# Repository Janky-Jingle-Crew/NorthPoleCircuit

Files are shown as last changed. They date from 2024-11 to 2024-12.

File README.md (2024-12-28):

{% comment %}

# North Pole Circuit
Also available on [janky-jingle-crew.com/NorthPoleCircuit](https://janky-jingle-crew.com/NorthPoleCircuit/)

{% endcomment %}

Merry Christmas, and a Happy New Year! This year, we present the first *Dual-core, 32-bit, high-speed, RISC-V, USB-C, hyper-festive, magnetic propulsion **christmas card!***

North Pole Circuit (https://www.youtube.com/watch?v=rN7HYXmgxzk)

(Click on image to watch demo video)

Featured on [Hackaday.com](https://hackaday.com/?p=739494), [hackster.io](https://www.hackster.io/news/racing-toward-christmas-4728aa6665af)

## User Guide

Plug in a USB-C cable, place the card on a flat surface, and put the deer and the sleigh onto the track. The three buttons at the bottom control the speed, there are three levels for each direction. The upper music button plays a Christmas Jingle accompanied by a small "dance".

## Working Principle
The propulsion can by explained by the reaction force from the [Lorentz force law](https://en.wikipedia.org/wiki/Lorentz_force) or [Magnetic forces](https://en.wikipedia.org/wiki/Force_between_magnets#Magnetic_force_due_to_non-uniform_magnetic_field), which acts orthogonally to the directions of both the current flow and the magnetic field of the magnet. Both seem to give the correct force vector, maybe someone smarter can figure out which one it actually is. By using magnets with poles aligned vertically (top and bottom) and positioning the PCB traces perpendicular to the track’s direction, the magnets experience a forward or backward force along the track based on the current direction.

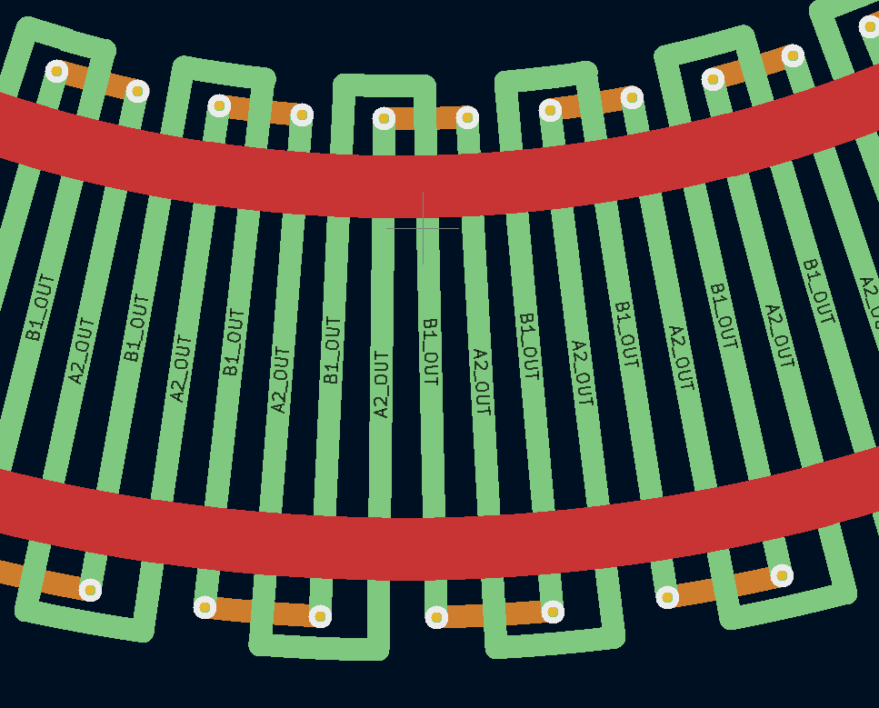
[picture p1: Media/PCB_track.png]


The tracks (A and B) are driven with two sinusoidal waveforms with a 90-degree phase shift between them, similar to microstepping a bipolar stepper motor. A guard rail is also added to keep the magnets centered during curves. The guard rails run along the outside of the track (parallel with track direction) which means an inwards force is generated instead. Reverse propulsion is achieved by simply stepping the sinusoidal in the other direction.
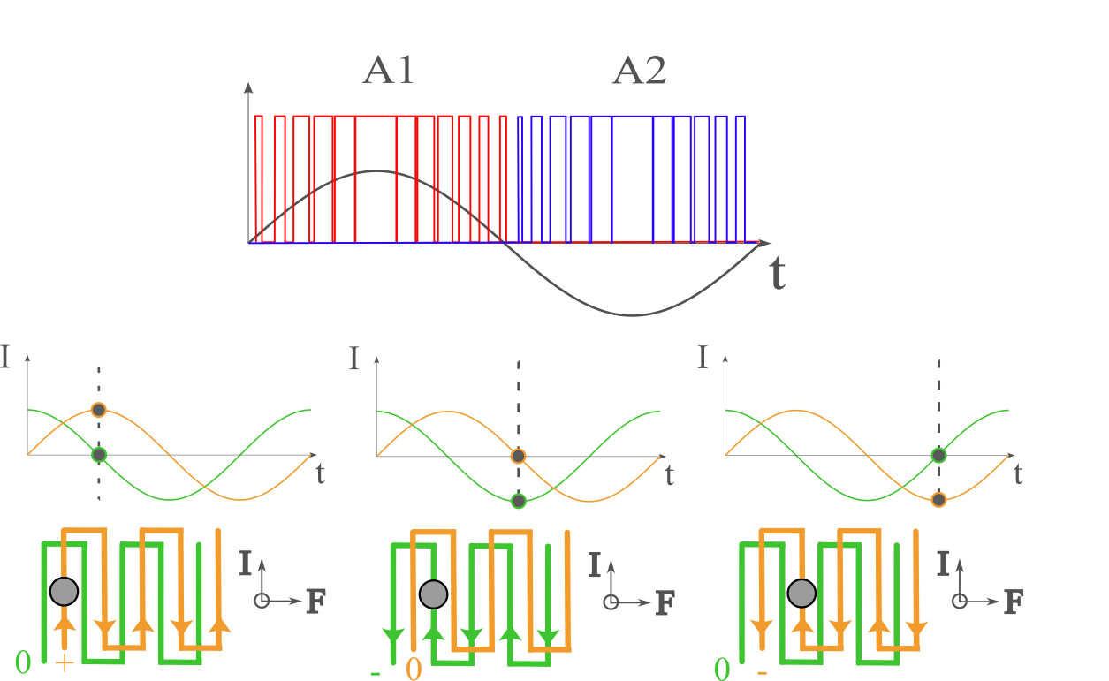
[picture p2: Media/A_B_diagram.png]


For more detailed explanations of the working principles, refer to **Jeff McBride’s** [blog post](https://jeffmcbride.net/gauss-speedway/).

## Design
The PCB consists of the phase tracks, guard rail, driver circuit and decoration circuit. The phases and guard rail are generated by Jeff's [curvycad](https://github.com/mcbridejc/curvycad/tree/main) plugin for KiCad. A 4 layer board was used for this, with 1 oz inner copper weight to reduce phase resistance. The driver circuit and the decoration circuit each have their own CH32 microcontroller, which communicate with each other using I2C. This was mainly done because a lack of timer modules.

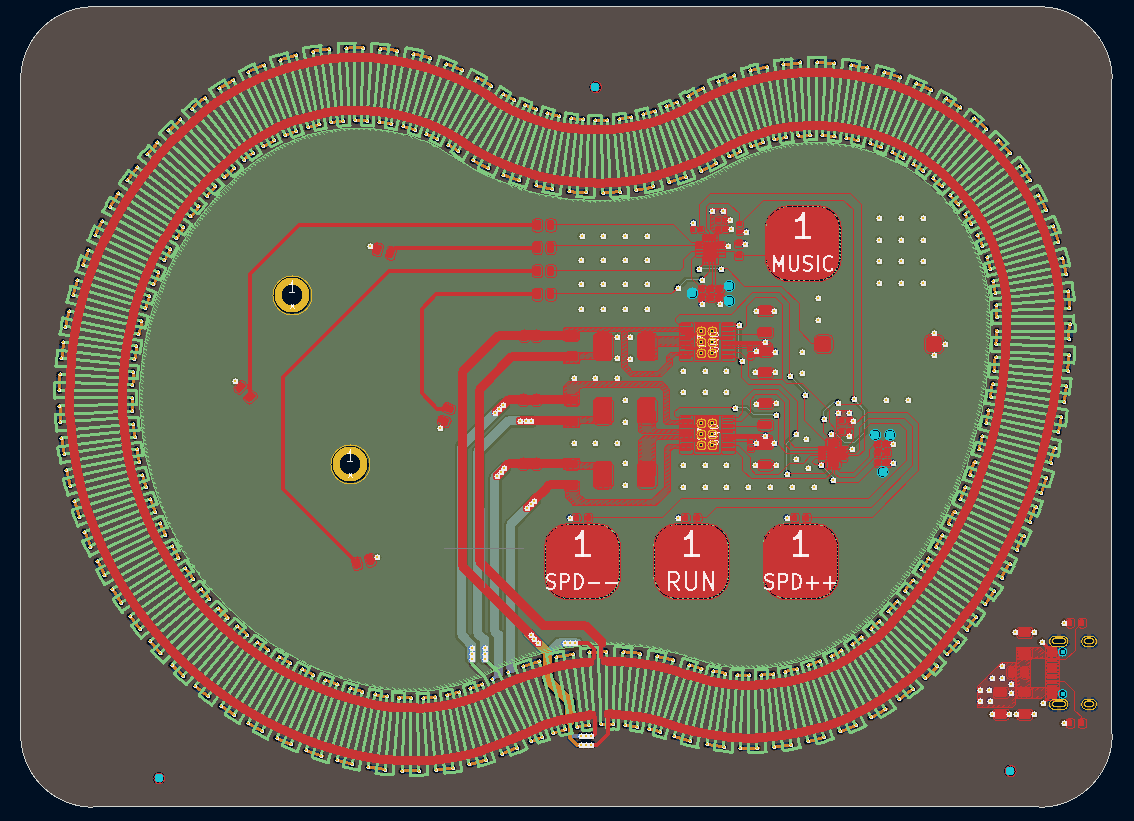
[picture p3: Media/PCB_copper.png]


### Driver circuit
The driver circuit controls the phase tracks and guard rails. The design is heavily based on Jeff’s design with some modifications for cost-effectiveness and USB compatibility:

* Power Supply: Utilizes 5V USB-C input instead of a barrel jack plug. The total current draw when moving is 500 mA.
* Microcontroller: Replaces the STM32 with the CH32V003, which is cheaper, ~20 cents! It is also 5V compatible.
* Motor Drivers: Uses DRV8833 motor drivers instead of ZXBM5210 for lower driver resistance (0.3 Ohms vs 1.2 Ohms), making the track a bit more efficient.

### Decoration circuit
A separate circuit using another CH32V003 handles LED control and buzzer music.

* CH32V003 microcontroller: Used for controlling decorative elements.
* I2C Communication: Links the decoration circuit with the driver circuit to synchronize dance.
* Buzzer: Plays a short Christmas jingle.
* LEDs: PWM brightness control through GPIOs for the 3D-printed village decoration. 

## Manufacturing

This year we made a total of 50 cards, all manufactured and assembled by JLC PCB. Each PCB then had decorations with trees and cottages attached, got rubber feet mounted, had one sleigh and one deer attached, was programmed, and was finally tested.

   

### Trees and cottages
The trees, cottage and ground are all one solid 3D-print, with a touch of white matte primer spray paint from above. Here, it is printed in 'army brown' PLA @ 0.2 mm layer height. Rectangular holes under the cottages give space for LEDs to illuminate them. This print was mounted to the PCB with 2 * M2.5x4mm screws.

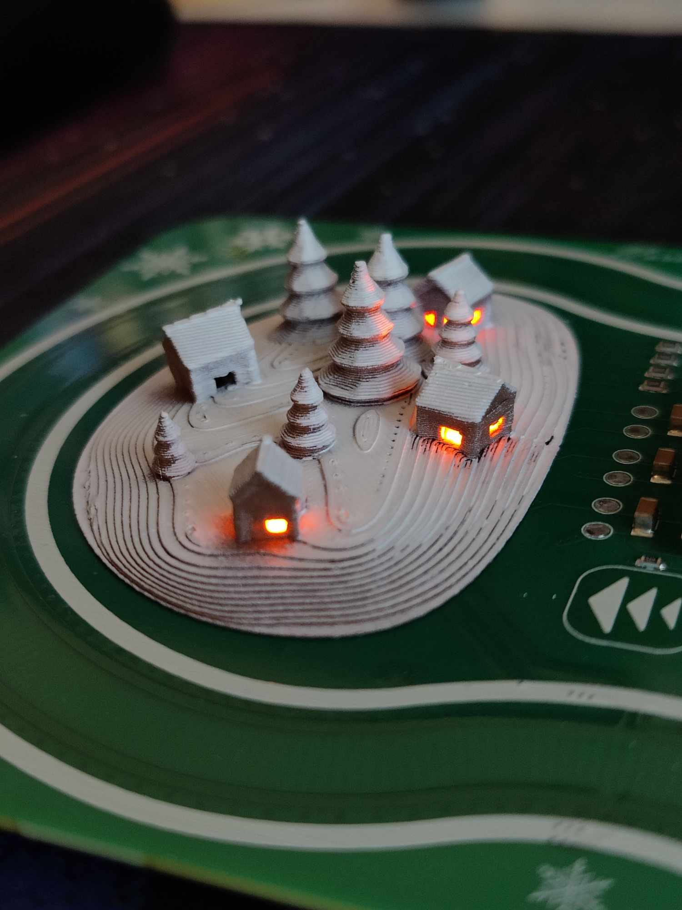
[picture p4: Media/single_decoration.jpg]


### Sleigh and reindeer
The sleigh and reindeer are also 3D-printed, but are a bit different. The sleigh is one print with multiple filaments, while the deer consists of two different; a white base for the magnets and the reindeer itself in the same brown filament as the trees.

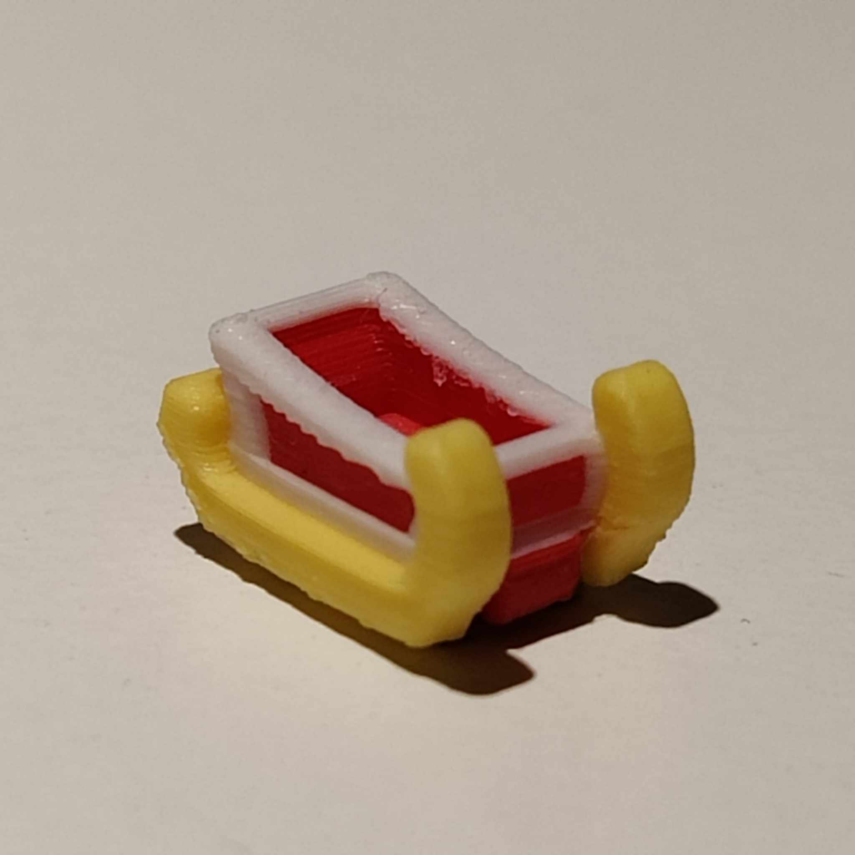
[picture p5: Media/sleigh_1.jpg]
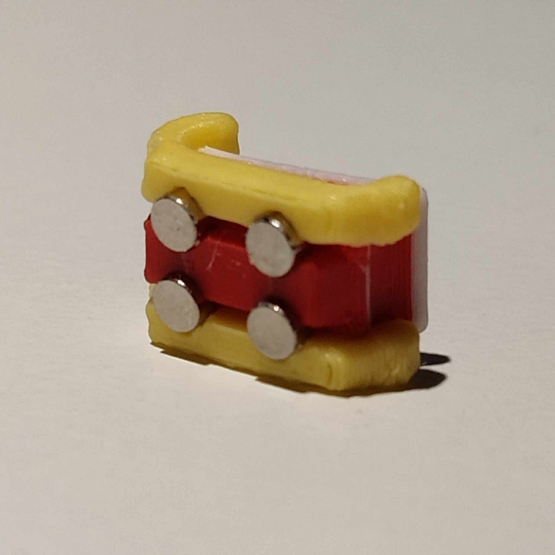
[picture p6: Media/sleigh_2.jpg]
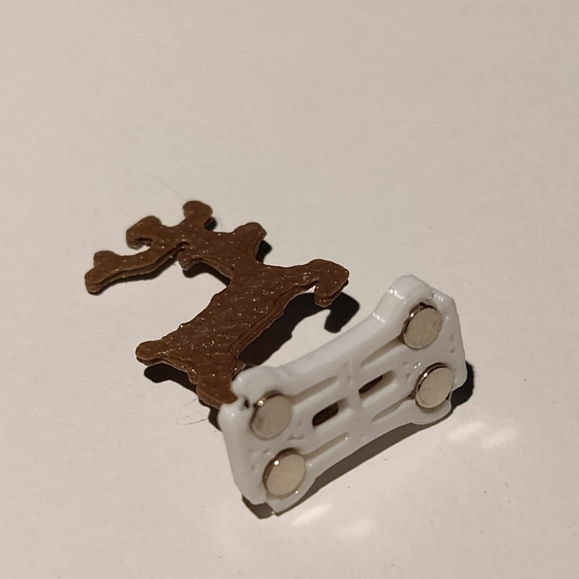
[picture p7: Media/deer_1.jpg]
          

Mounting the magnets (2x1 mm, N42/N52) was quite tricky, and it is crucial to orient them correctly! We fine-tuned the models so that the magnets would press-fit into place. For the sleigh, a small drop of super glue was applied to the magnets before being pressed into the sleigh using a specialized fixture. The reindeer is simpler since the base is flat, the magnets were pressed in before the reindeer itself was mounted on top.

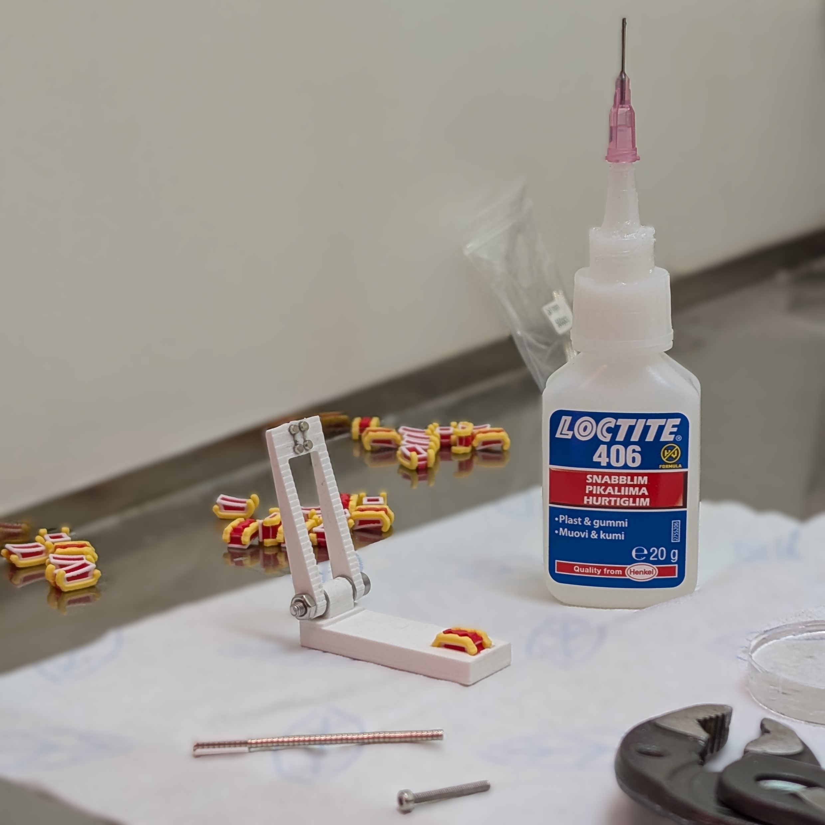
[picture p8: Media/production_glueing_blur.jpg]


## FAQ
### How do I reproduce this?
#### PCB
The production files for the PCB are provided in PCB/production/. 
Upload the gerber, BOM and position files to JLCPCB to order the boards. 
Some important special options:
* LeadFree HASL (Avoid lead poisoning your friends and family)
* 1 oz Inner Copper weight (Needed to reduce phase resistance)
* Layer Sequence (JLCPCB usually gets it right from the gerber names but it's safer to specify them)
    * L1 F_Cu
    * L2 In1_Cu
    * L3 In2_Cu
    * L4 B_Cu
* Impedance control (Minimize distance/prepreg between L1 and L2 = Stronger field strength)
    * Choose one of these:
        * JLC041611-7628 (0.2104mm prepreg, allows for cheaper economic assembly, used in ours)
        * JLC041611-3313 (0.092mm prepreg, standard assembly required)
        * JLC041611-1080 (0.069mm prepreg, standard assembly + extra fee required)
#### Flashing
A WCH-LinkE or similar programmer is required, see [ch32v003fun](https://github.com/cnlohr/ch32v003fun?tab=readme-ov-file#ch32v003fun).
Some type of 6 pin (2x3 1.27mm pitch) pogo connector is also required (we use a TagConnect TC2030NL).
Or you can solder wires directly to the pads. Only SWDIO and GND need to be soldered (power from USB instead to ensure programmer does not source too much current). 

### How much did this all cost?
For 50 boards, the cost breakdown **(VAT & shipping excluded)** looks like this:
* PCBs $140
* Components $127
* Assembly Fee $46
* Filament & Spray paint $40
* Magnets $35
* Screws $10

Total cost was 398 USD which rounds out to roughly 8 USD per card. 
**Do note that JLCPCB can be quite costly for smaller batches (~$90 for 5 populated boards).** 

### More technical tidbits
See the discussion in [#1](https://github.com/Janky-Jingle-Crew/NorthPoleCircuit/issues/1) with **cnlohr**. 

## Credits

Special thanks to **Jeff McBride**, this project was heavily inspired by his awesome [Gauss speedway](https://jeffmcbride.net/gauss-speedway/).

Also thank you **cnlohr** for the [ch32v003fun](https://github.com/cnlohr/ch32v003fun) framework which was used to program the microcontrollers.

Thanks to **Ida Udd** for the beautiful design of the reindeer and **Rikard Karlsson** for helping us 3D print the sleighs in beautiful multi-color detail. 

## Contributors
The Janky Jingle Crew 2024 consists of: 

 - [Daniel Quach](https://github.com/Muoshy): Project lead, PCB, Code, Assembly, Documentation
 - [Johan Wheeler](https://github.com/johanwheeler): PCB Track, sleigh design, Assembly
 - [Gustav Abrahamsson](https://github.com/GustavAbrahamsson): Decorations, sleigh design, Assembly
 - [Adam Anderson](https://github.com/adaand00): Code, sleigh design, Assembly, Documentation

## Previous years

Go to [janky-jingle-crew.com](https://janky-jingle-crew.com)

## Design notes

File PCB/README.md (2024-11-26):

# PCB

This folder contains the KiCAD project for the PCB, including manufacturing 
files.

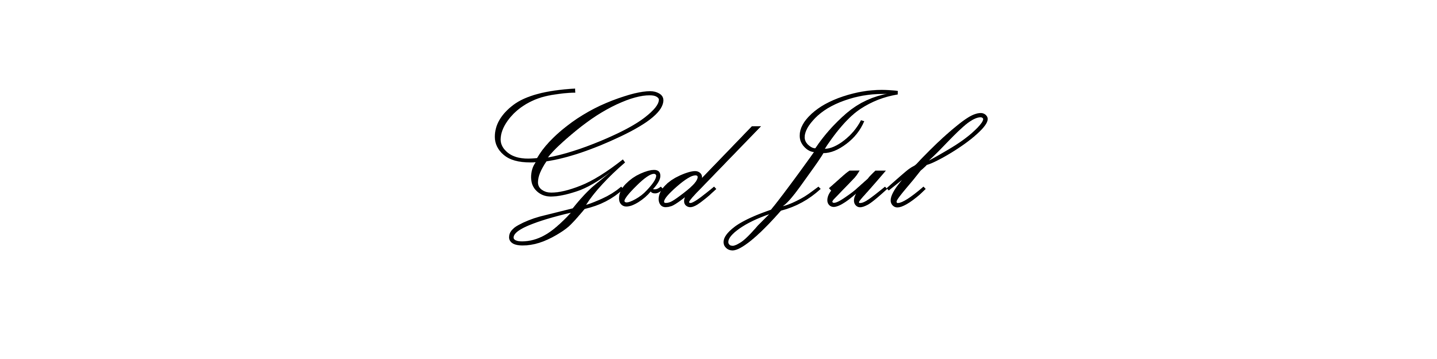
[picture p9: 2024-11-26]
PCB/Pictures/Kunsler Script 350/text_god_jul.png

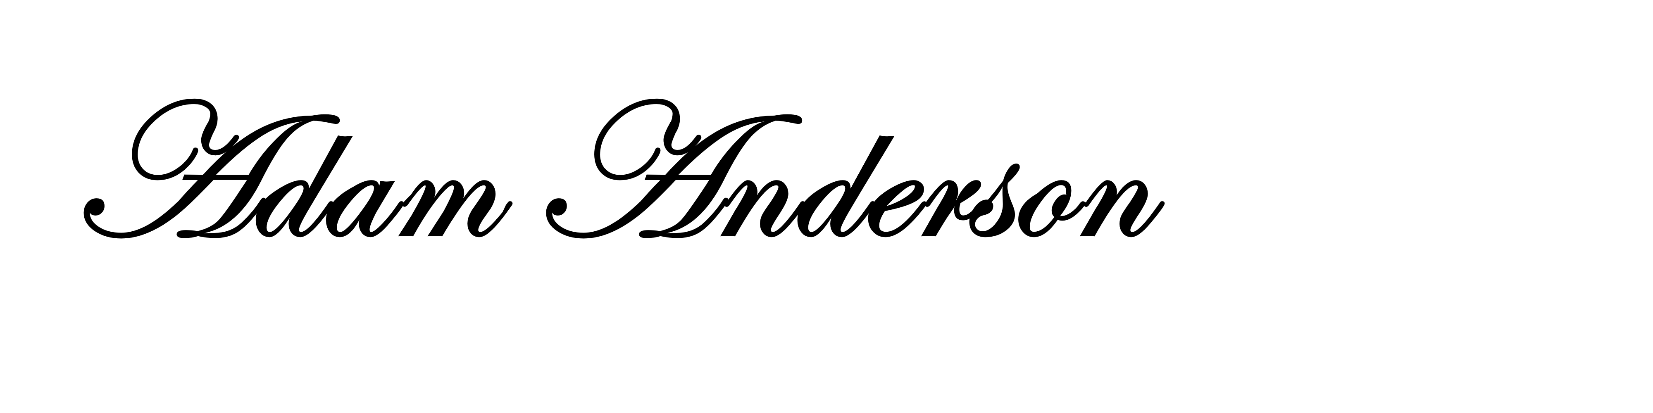
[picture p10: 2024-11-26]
PCB/Pictures/Edwardian Script ITC 350/text_AA.png

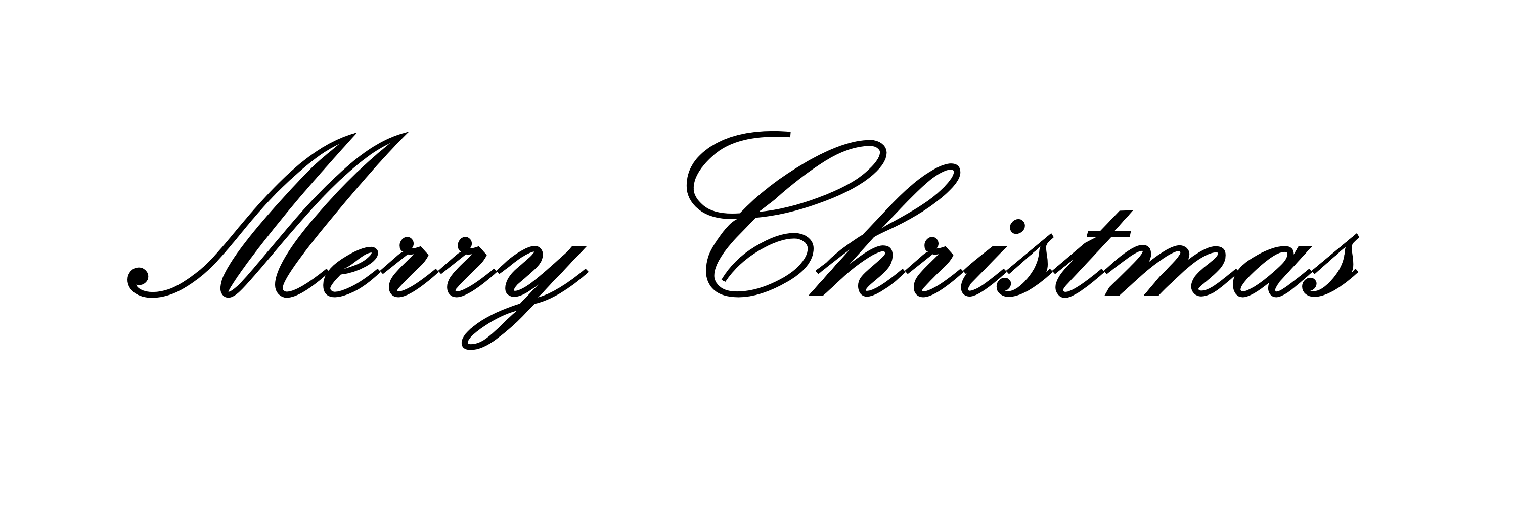
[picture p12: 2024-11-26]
PCB/Pictures/Kunsler Script 350/text_merry_christmas2.png

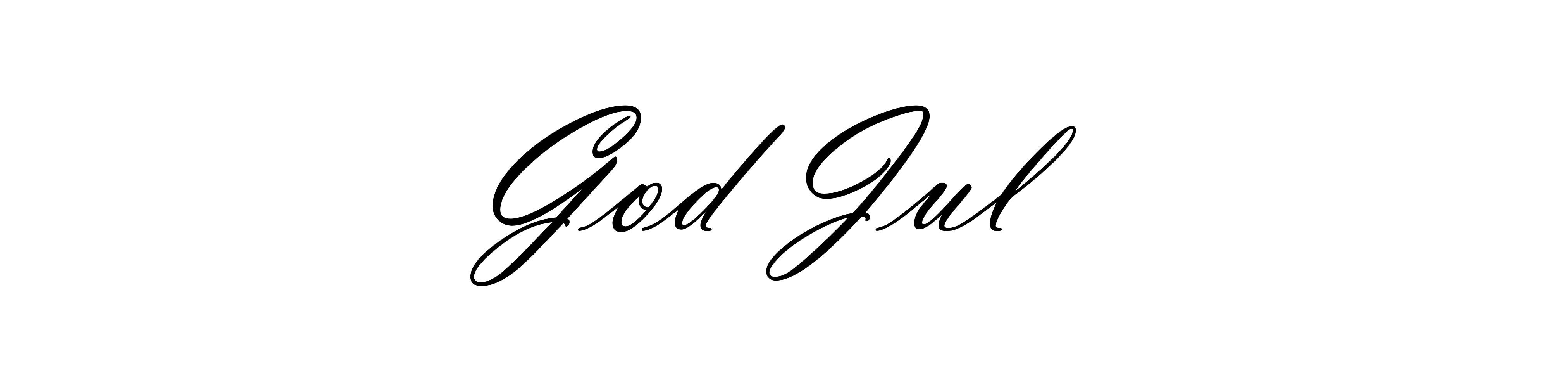
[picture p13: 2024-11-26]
PCB/Pictures/Vladimir Script 350/god jul.png

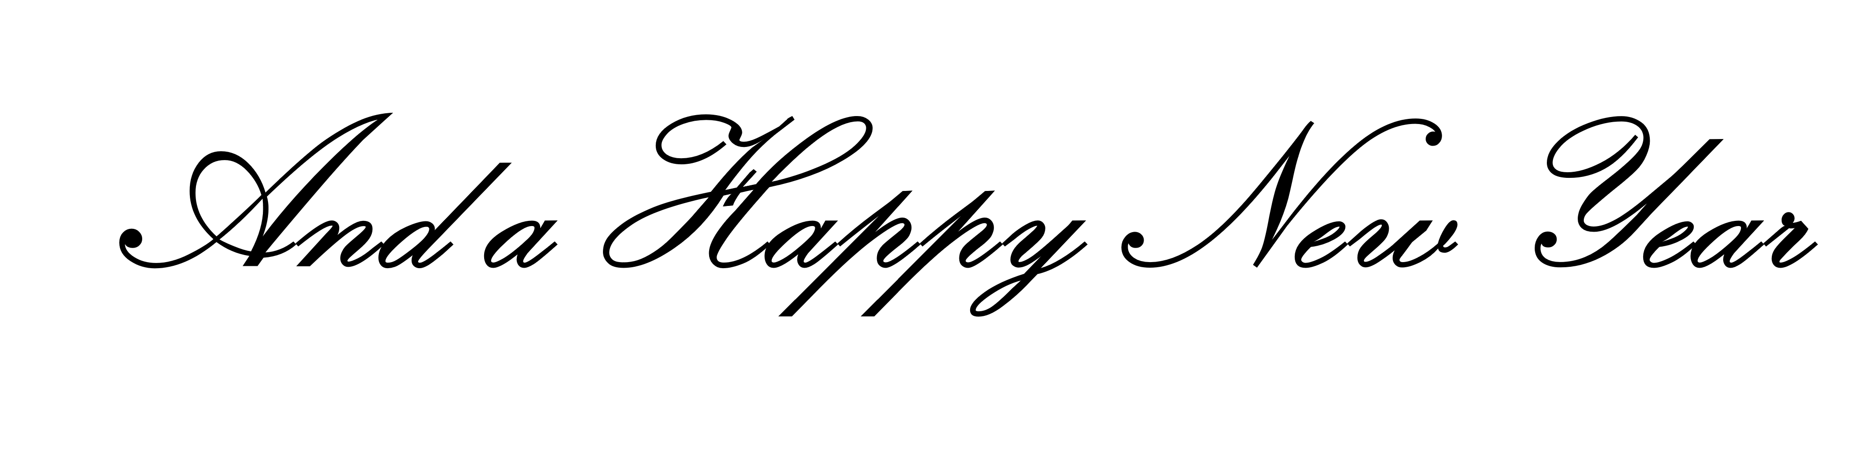
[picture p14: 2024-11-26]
PCB/Pictures/Kunsler Script 350/text_and_a_happy_new_year2.png

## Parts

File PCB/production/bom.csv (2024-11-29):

Designator | Footprint | Quantity | Value | LCSC Part #
BZ1 | FUET-1325 | 1 | FUET-1325H | C2982583
C1, C11, C12, C2, C3, C4, C7, C8 | 1206 | 8 | 10uF | C13585
C10, C6 | 0402 | 2 | 10nF | C15195
C13, C14, C15, C16 | 0402 | 4 | 100n | C1525
C5, C9 | 1206 | 2 | 2.2uF | C50254
D1, D2, D3, D4 | 0805 | 4 | LED | C5878906
F1 | 0805 | 1 | 500mA | C269104
J1 | USB_C_Receptacle_HRO_TYPE-C-31-M-12 | 1 | USB_C_Receptacle_USB2.0_16P | C165948
L1, L2, L3 | SMMS0650-101M | 3 | SMMS0650-101M | C2894722
R1, R2 | 0603 | 2 | 5k1 | C23186
R10, R7, R8, R9 | 0603 | 4 | 510k | C23192
R11, R12 | 0402 | 2 | 3.3k | C25890
R3, R4, R5, R6 | 0805 | 4 | 180R | C25270
U1, U2 | HTSSOP-16-1EP_4.4x5mm_P0.65mm_EP3.4x5mm_Mask2.46x2.31mm_ThermalVias_Larger | 2 | DRV8833PWP | C50506
U3, U4 | QFN-20-1EP_3x3mm_P0.4mm_EP1.65x1.65mm | 2 | CH32V003FxUx | C5299908

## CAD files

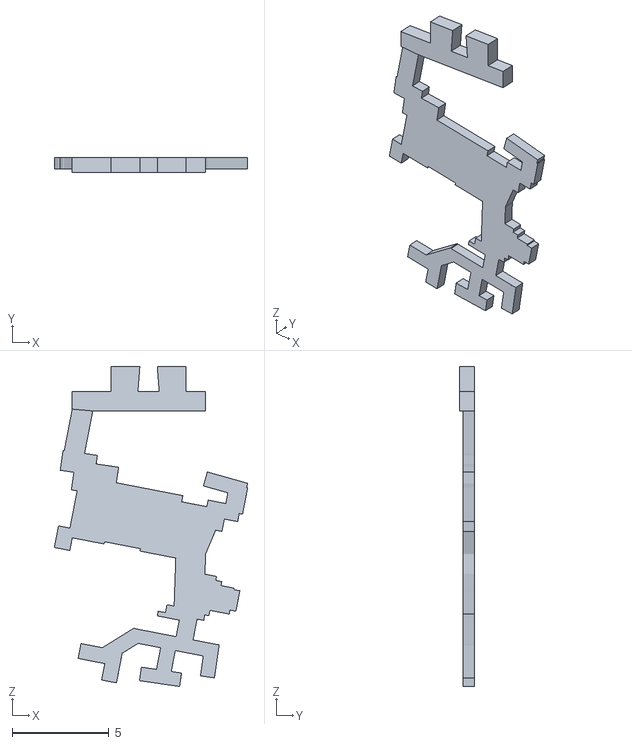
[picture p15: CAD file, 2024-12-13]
CAD/STL/deer.stl
10.0 x 0.8 x 16.6

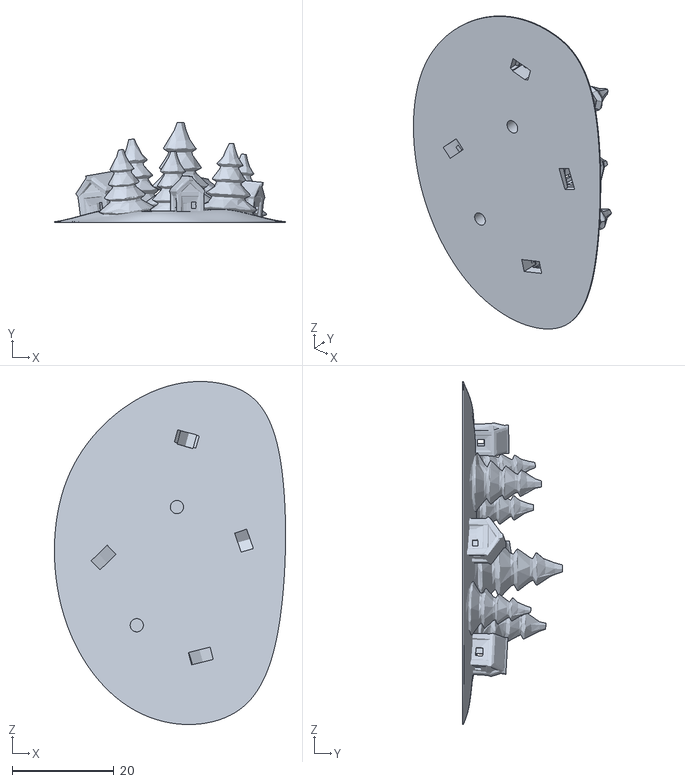
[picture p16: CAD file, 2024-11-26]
PCB/CAD/STL/decoration.stl
45.4 x 19.7 x 67.4

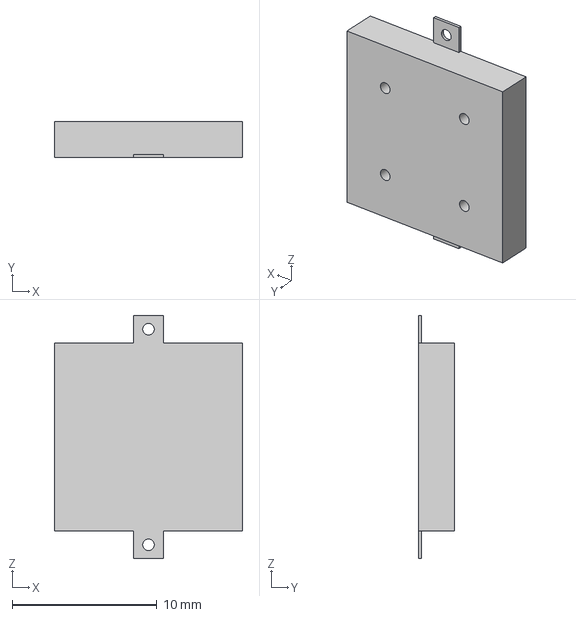
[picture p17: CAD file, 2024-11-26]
PCB/cust_fp/buzzer_C391038.step
13.0 x 2.50 x 16.8 mm

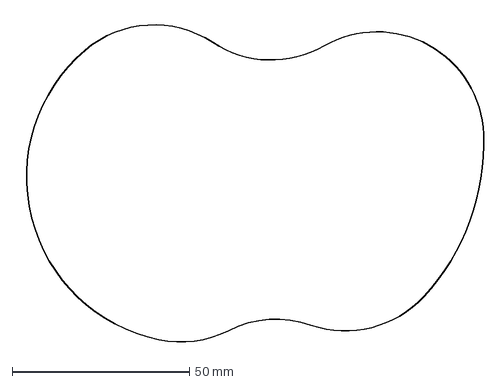
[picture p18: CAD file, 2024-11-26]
PCB/track_alignment/track.dxf
132.5 x 92.6 mm

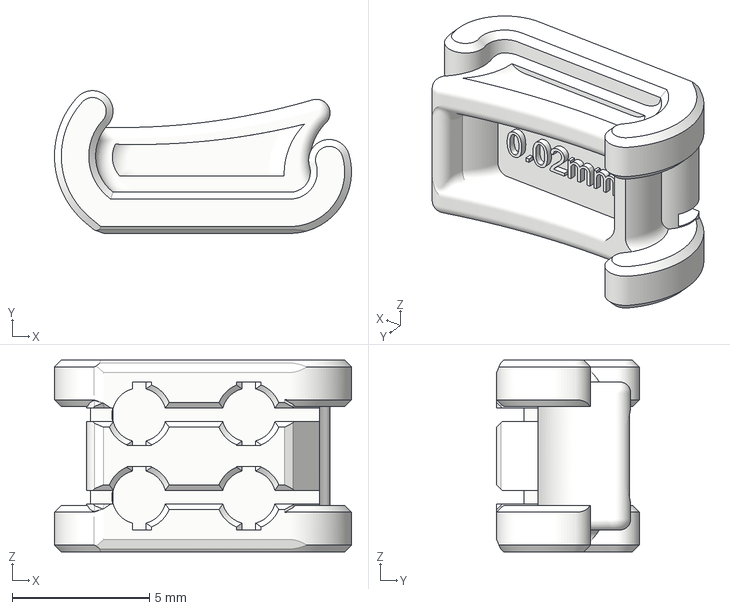
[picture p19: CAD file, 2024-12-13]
CAD/STL/Sleigh.3mf
10.8 x 5.21 x 7.00 mm

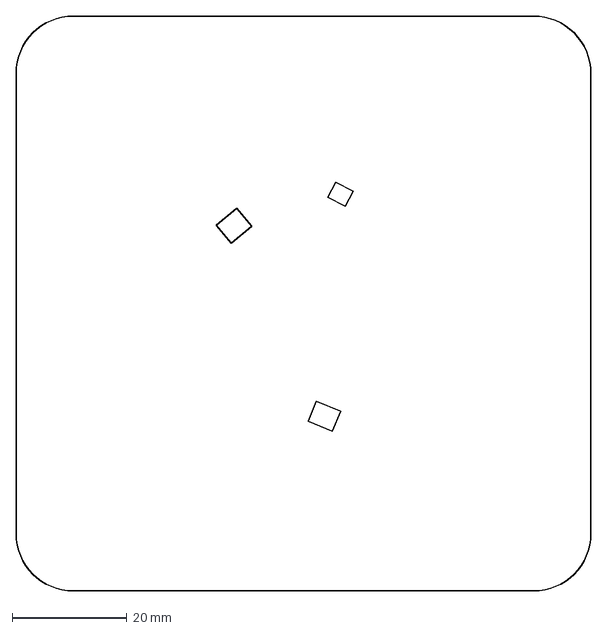
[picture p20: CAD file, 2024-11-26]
PCB/track_alignment/house_positions.dxf
100.0 x 100.0 mm

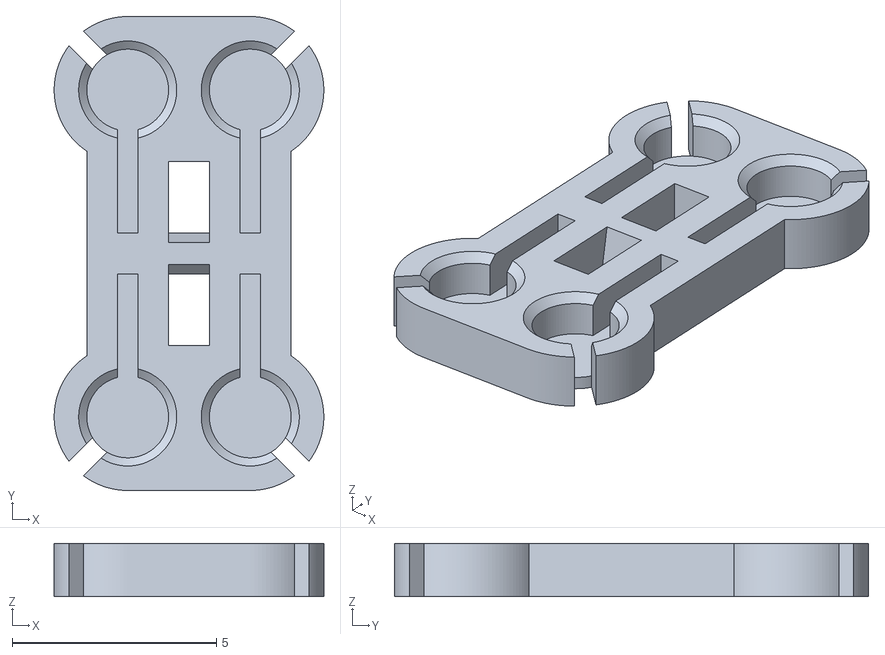
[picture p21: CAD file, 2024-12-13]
CAD/STL/Shuttle.stl
6.60 x 11.6 x 1.30

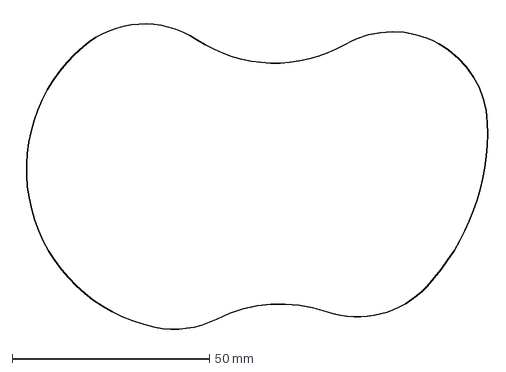
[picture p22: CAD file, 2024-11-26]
PCB/track_alignment/track_min_6mm.dxf
120.0 x 79.9 mm

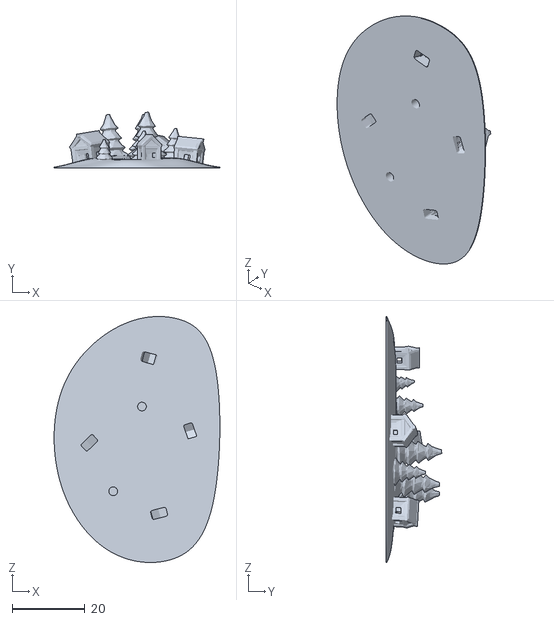
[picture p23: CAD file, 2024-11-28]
CAD/STL/decoration.stl
45.4 x 15.2 x 67.4

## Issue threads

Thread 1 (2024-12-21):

Just some questions

cnlohr, 2024-12-21:
Actually I've got a few questions and comments.

1. I downloaded your kicad files, would be cool for you to include a PCB shot in the readme.
2. The readme itself at the beginning is a little corrupty, may want to fix it.  Github no longer allows embedding of youtube embeds that way, you have to now do it this way:
```
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
```
I.e.
```
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
```

The questions:

1. I have never done anything with Lorenz forces, but, wouldn't it be better if there was not copper fill under the track (on B.Cu and In2)?
2. I am having a hard time following the mechanism for how your track is designed, especially the top layer, it feels really confusing that it would wrap around and backtrack on the outside instead of go around twice?
3. Would you be willing to draw up your waveform generation? Or even have a capture of G1_OUT/G2_OUT, B1_OUT/B2_OUT, A1_OUT, A2_OUT.
4. I notice you have UART on your programming header.  Did you find anything wrong with the printf-over-swio, in 003fun?

Muoshy, 2024-12-21:
Hi cnlohr,
Thanks for the feedback and also the great resources in ch32v003fun, been an absolute pleasure working with it.

1. Good suggestion, will definitely add one.

2. The readme is used to render [this page](https://janky-jingle-crew.com/NorthPoleCircuit) at the same time.
Because of markdown/HTML conflicts, it's looking a bit janky right now. We will probably separate them later on.

Great questions. had to think a bit for these. I will do my best to answer them.

1. The copper fills are mainly there for lazy power and GND routing. Good question, I also think it would be better but not sure how.... On top of my head I can think of eddy currents and field distribution.

**Eddy currents:**
Eddy currents will definitely be induced in the copper fills. These are proportional to the rate of change in the B-field (dB/dt).
I can see three sources of these.
* The current ripple on the sinusoidal PWM will generate a changing B-field. High frequency (100 kHz) but low amplitude due to extra inductor and high PWM frequency. Low dB/dt / eddy losses here.
* The phase currents will also generate a changing B-field. Higher amplitude but low frequency (~100 Hz range). Should also be low dB/dt / eddy losses.
* The magnet movement. Definitely has the highest field strength but unsure about the dB/dt for this one. Pretty sure we also get some Lenz Law action here working against the magnet movement a bit. Removing the copper fill would definitely help here....

**Field distribution:**
Initially, I assumed the copper would act as a "shield," concentrating/squeezing the field near the fill. However, I later realized that copper is non-ferrous, and since we're dealing with B-fields, it shouldn't influence the B-field distribution and the resulting Lorentz force. Will affect E-fields though!

Open to discussion regarding these points. Could definitely be a few hiccups in my thought process on these questions.

2. The guard rail (top layer) needs to wrap around so we get the current on the outside and inside rails flowing in opposite directions. Otherwise, one rail will generate an inwards force and the other one will generate an "outside" force. Here's a really bad sketch (might be wrong force direction but principle still holds). Hopefully it makes sense. I will try to add a sketch of the A/B phase propulsion to the readme as well.
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

3. Definitely! I will scope out some signals and add it to the readme.
It's just PWM with the duty cycle following a sine wave to control the phase currents. A and B are then phase shifted 90deg. So when A is max duty cycle, B will be 0. The guard rail just has a fixed duty cycle to generate a constant inwards force.

4. I never had the time to test the printf-over-swio functionality but saving 2 pins is definitely helpful.
Does it work with the WCH-LinkE and would you mind pointing me to the example?

cnlohr, 2024-12-21:
1/2. I never would have thought to use README to feed a website.  That's a pretty good idea.  Gosh I wish github would loosen up some of their readme restrictions.  For instance, I really wish you could direct-link off-github im
ages, etc.

1. I still struggle to think through the difference between E and B fields, and separating them in my head. Thank you so much for the clarification.
2. About the top rail, it just feels weird to have an inversion at the bottom. I just opened up gimp and started drawing what I meant, but then I realized, I couldn't draw it.  Like even though what you have feels intuitively wrong to me, I think it's right.  That said - would it be better to do something like this?  Or is this what you did?
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
3. I would really appreciate it.  I don't know I'll ever do a project that uses this but, I would love to more deeply understand this in case I can find an application.
4. `debugprintfdemo` -- And it's not just saving pins, it's more for the convenience.

Muoshy, 2024-12-21:
1. No worries, I stumbled into the same E/B field pitfall when I first tried to answer that question.

2. I understand your struggles, we also had ponder a lot when routing the guard rails for the first time.

I think your version could work. In your case, you are paralleling the inner & outer loops and effectively halving the guard rail resistance. This is great and would lower power consumption even more. However, this also means the inner and outer loops will have different currents. The inner loop will generate a stronger Lorentz force which unfortunately is the opposite of what we want. Ideally, the outer loop should be a bit stronger to counteract centripetal effects.

I did some quick calculations and in our case this comes out to roughly 30% more current in the inner loop. However, when you factor in driver resistance (0.3/2 ohms as guard driver is paralleled), the difference shrinks to only 15%.  With some other parasitics  included or worse drivers, I believe your solution might be better.

Small detail: It might be good to overlap the guard rail crossings on top of each other like this. This should cancel out the Lorentz forces when the magnet is right on top of the guard rail crossings. Seems to work well in our case but we haven't tried without the overlap.
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

4. Absolutely! I will ping the thread/issue once it's added to the readme.

5. Great, I will take a look at it for further CH32 projects.

Muoshy, 2024-12-22:
Here is a diagram of the A/B PWM waveforms along with the current directions for three "steps", it should also be in the readme now. Hopefully it makes sense. Let me know if I can close the issue or if you have additional questions.

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

dazhbog, 2024-12-24:
Can you please put the YouTube video at the first line of the readme/repo description? Way cooler to see it in action first! Also on your website its not clear that the first image is an actual link to YouTube.

Amazing project!

cnlohr, 2024-12-27:
Oh gosh thank you for all this clarification!  I could recommend you add this to your readme, it would be really helpful if this info was indexed on the internet better.

cnlohr, 2024-12-29:
Aww! It looks great! Thanks for adding it. Happy holidays!

Closed 2024-12-28.

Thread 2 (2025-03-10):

Cannot Import Custom Track

annoyedmilk, 2025-03-10:
## Issue: Inkscape-Generated DXF Files Not Compatible with Modified GaussSpeedway Track Generator

### Description
I'm attempting to replicate the North Pole Circuit project and am facing an issue with importing custom tracks. I've successfully imported the provided track file (`PCB/track_alignment/track.dxf`) using a modified version of the GaussSpeedway track generation script, but I cannot successfully import tracks I've created in Inkscape and exported as DXF.

### Steps to Reproduce
1. Created a custom track design in Inkscape
2. Exported the track as a DXF file
3. Used my modified version of the GaussSpeedway script (https://github.com/mcbridejc/GaussSpeedway/blob/main/generate_track.py)
4. Attempted to import into KiCad 9.0 using my plugin based on the script

### My Environment
- KiCad version: 9.0
- Modified GaussSpeedway script [track_generator.py.txt](https://github.com/user-attachments/files/19163966/track_generator.py.txt)
- CurvyCAD plugin installed

### My Plugin Configuration
I've created a modified version of the plugin that:
- Updates KiCad API calls for compatibility with KiCad 9.0
- Adds support for selecting custom DXF files

### What Works
- Successfully imported the original track file (`PCB/track_alignment/track.dxf`) from the NorthPoleCircuit repository
- The plugin works correctly with the provided DXF files

### What Doesn't Work
- Custom tracks created in Inkscape and exported as DXF fail to import properly

### Additional Details
I suspect there might be specific requirements for how paths need to be structured in the DXF file to be properly interpreted by the CurvyCAD library. The provided track.dxf works perfectly, but my Inkscape-generated DXFs do not, suggesting there's a format difference or specific path attribute that I'm missing.

### Questions
1. What specific format requirements must the DXF files meet to be compatible with the CurvyCAD library?
2. Are there particular Inkscape export settings I should use when creating DXF files for this purpose?

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

### Related Links
- Original GaussSpeedway script: https://github.com/mcbridejc/GaussSpeedway/blob/main/generate_track.py
- North Pole Circuit track DXF: https://github.com/Janky-Jingle-Crew/NorthPoleCircuit/blob/main/PCB/track_alignment/track.dxf

annoyedmilk, 2025-03-11:
I've been investigating why my Inkscape-generated DXF files aren't working with the CurvyCAD library, and I've found the root cause.

After reviewing the CurvyCAD repository (https://github.com/mcbridejc/curvycad), I discovered that the library has very specific requirements for DXF files:

## DXF Path Requirements for CurvyCAD

1. **Path Continuity**: All elements must form a single continuous path with no extra or disconnected lines.

2. **Tangency Requirement**: Each segment must be tangent to adjacent segments. Lines must be connected via arcs with proper tangent constraints.

While Inkscape technically exports as LWPOLYLINEs, it doesn't create the type of geometrically precise, tangent-constrained paths that CurvyCAD expects. The library needs actual arc entities (or LWPOLYLINEs with proper bulge values) and mathematically tangent connections between segments.

The original track.dxf that works was likely created with these constraints in mind in a proper CAD tool, which explains why my Inkscape exports aren't compatible despite appearing to use the right settings.

Sorry for the confusion in my initial report.

Closed 2025-03-11.

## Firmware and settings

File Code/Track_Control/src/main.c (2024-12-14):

#include "ch32v003fun.h"
#include <stdio.h>
#include "stdbool.h"
#include "stdlib.h"

#include "buttons.h"
#include "PhasePWM.h"
#include "i2c_slave.h"

// Sign of integer, returns 1 or -1
#define sign(i) ((i >= 0)*2 - 1)

// Clamping
#define MIN(a,b) (((a)<(b))?(a):(b))
#define MAX(a,b) (((a)>(b))?(a):(b))
#define CLAMP(x, lower, upper) (MIN((upper), MAX((x), (lower))))

// Array Length
#define len(a) (sizeof(a) / sizeof(*a))


// Ramp frequency
#define SYSTICK_INT_HZ (50)

// Maximum interval
#define BASE_INTERVAL 1000 

// I2C slave addr
#define I2C_ADDR 0x77

volatile int speed_count = 0;
volatile int8_t speed_idx = 2;
volatile uint8_t i2c_registers[2] = {0x00};
volatile int step_interval = BASE_INTERVAL;
volatile bool music_running;
volatile uint8_t music_note;
volatile uint8_t last_music_note;

// Step interval = BASE_INTERVAL / speed_values 
// Ex. 60 -> 1 step per 16 ticks
// 20 -> 1 step per 50 ticks 
static const int speed_values[] = {-50, -35, -20, 20, 35, 50};

track_state_t track_state;

volatile struct {
	int speed;
	int target_speed;
	uint32_t step_interval;
} ui_state;

void systick_init(void);

void onWrite(uint8_t reg, uint8_t length) {

	if(i2c_registers[0] == 0xff){
		music_running = false;
	}else{
		music_running = true;
		track_enable(&track_state);

		if(i2c_registers[0] == 0){
			ui_state.speed = 0;
		}else{
			last_music_note = music_note;
			music_note = i2c_registers[0];

			if(music_note > last_music_note){
				ui_state.speed = 20 + music_note/2;
			}else{
				ui_state.speed = -20 - music_note/2;
			}
		}
	}

	printf("%x \n", i2c_registers[0]);
	//printf("%x \n", i2c_registers[1]);
}

int main()
{
	SystemInit();

	// Turn on interrupt nesting and hardware stack
	uint32_t sys = __get_INTSYSCR();
	__set_INTSYSCR(sys | 0b11);

	// Init phase PWM timer
	track_init(&track_state);

	// Init button gpios and NVIC
	buttons_init();

	ui_state.speed = 0;
	ui_state.target_speed = speed_values[speed_idx];
	track_enable(&track_state);
	systick_init();

	//I2C
    SetupI2CSlave(I2C_ADDR, i2c_registers, sizeof(i2c_registers), onWrite, NULL, false);
	//I2C

	PhasePWM_initTim2_IRQ();


	while(1) {
		buttonPress_t pressed = buttons_read_rising();

		switch (pressed)
		{
		
		case buttonSpeedDec:
			speed_idx -= 1;
			speed_idx = CLAMP(speed_idx, 0, len(speed_values)-1);
			ui_state.target_speed = speed_values[speed_idx];
			break;

		case buttonSpeedInc:
			speed_idx += 1;
			speed_idx = CLAMP(speed_idx, 0, len(speed_values)-1);
			ui_state.target_speed = speed_values[speed_idx];
			break;

		case buttonStartStop:
			if(track_state.enabled){
				ui_state.target_speed = 0;
			}else{
				track_enable(&track_state);
				ui_state.target_speed = speed_values[speed_idx];
			}
			

		default:
			break;
		}

		if(pressed != buttonNone){
			//printf("Pressed button: %d\n", pressed);
			printf("speed_idx: %d\n", speed_idx);
		}

		Delay_Ms(50);
	}
}


/*
 * Start up the SysTick IRQ
 */
void systick_init(void)
{
	/* disable default SysTick behavior */
	SysTick->CTLR = 0;

	/* enable the SysTick IRQ */
	NVIC_SetPriority(SysTicK_IRQn, 0);
	NVIC_EnableIRQ(SysTicK_IRQn);

	/* Set the tick interval to 1ms for normal op */
	SysTick->CMP = (FUNCONF_SYSTEM_CORE_CLOCK / SYSTICK_INT_HZ) - 1;

	/* Start at zero */
	SysTick->CNT = 0;
	//ms_cnt = 0;

	/* Enable SysTick counter, IRQ, HCLK/1 */
	SysTick->CTLR = SYSTICK_CTLR_STE | SYSTICK_CTLR_STIE |
									SYSTICK_CTLR_STCLK;
}


/*
 * SysTick ISR just counts ticks
 * note - the __attribute__((interrupt)) syntax is crucial!
 */
void SysTick_Handler(void) __attribute__((interrupt));
void SysTick_Handler(void)
{
 	
	// move the compare further ahead in time.
	// as a warning, if more than this length of time
	// passes before triggering, you may miss your
	// interrupt.
	SysTick->CMP += (FUNCONF_SYSTEM_CORE_CLOCK / SYSTICK_INT_HZ);

	// Ramp speed
	if(track_state.enabled && (ui_state.speed != ui_state.target_speed || music_running)) 
	{
		
		if (ui_state.speed < ui_state.target_speed && !music_running) 
		{
			ui_state.speed += 1;
		} 
		else if (ui_state.speed > ui_state.target_speed && !music_running) 
		{
			ui_state.speed -= 1;
		}

		// Convert to step interval for linear speed conversion
		ui_state.step_interval = (abs(ui_state.speed) > 0) ? BASE_INTERVAL / abs(ui_state.speed) : 0;

		// Turn off track at stand still
		if(ui_state.target_speed == 0 && ui_state.speed == 0){
			track_disable(&track_state);
		}
	}
	
	
	// clear IRQ
	SysTick->SR = 0;

}


void TIM2_IRQHandler(void) __attribute__((interrupt));
void TIM2_IRQHandler(void)
{	
	// Clear IRQ
	if (TIM2->INTFR & TIM_UIF)
	{	
		TIM2->INTFR &= ~(TIM_UIF);
	

		// Motor advance PWM phase
		if(track_state.enabled && ui_state.step_interval > 0) 
		{	
			speed_count++;
			if(speed_count > ui_state.step_interval){
				track_step(&track_state, sign(ui_state.speed));
				speed_count = 0;
			}
		}
	}
}

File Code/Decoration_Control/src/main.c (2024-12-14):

#include "ch32v003fun.h"
#include <stdio.h>
#include "stdbool.h"

//#define WS2812BSIMPLE_IMPLEMENTATION

//#include "ws2812b_simple.h"
//#define WS2812BSIMPLE_NO_IRQ_TWEAKING
#include "buzzer.h"
#include "buttons.h"
#include "PhasePWM.h"
#include "i2c.h"

#define SYSTICK_INT_HZ (30)

track_state_t led_pwm_state;
music_state_t music_state;

enum comms {
	MUSIC_OFF = 255,
	MUSIC_NOTE_OFF = 0,
};

volatile struct {
	uint8_t guard_pwm;
	uint32_t speed;
	uint32_t note;
} tick_count;

int systick_count_max;

volatile struct {
	int speed;
	bool running;
	bool music;
} ui_state;

#define PORTC_NUM 2

void systick_init(void);

#define WALK_BIAS (MAX_DUTY*0.2)
#define SPEED_BIAS 0
#define SPEED_MAX 50
#define SPEED_RAND_RANGE 16


uint8_t buf[1] = {0x77};
#define TRACK_MCU_I2C_ADDR 0x77
#define TRACK_MCU_I2C_REG 0x00

// Write 1 byte to the track mcu via the I2C bus
void send_track(uint8_t val){
	buf[0] = val;
	i2c_write(TRACK_MCU_I2C_ADDR, TRACK_MCU_I2C_REG, buf, 1);
}

typedef struct walk_state walk_state_t;

struct walk_state {
  int32_t x;
  int32_t bias;
  int32_t min;
  int32_t max;
  walk_state_t * derivative;
};

walk_state_t walk_states[4] = {
  {0, WALK_BIAS, 0, MAX_DUTY, &(walk_state_t) {0, SPEED_BIAS, -SPEED_MAX, SPEED_MAX, NULL}},
  {0, WALK_BIAS, 0, MAX_DUTY, &(walk_state_t) {0, SPEED_BIAS, -SPEED_MAX, SPEED_MAX, NULL}},
  {0, WALK_BIAS, 0, MAX_DUTY, &(walk_state_t) {0, SPEED_BIAS, -SPEED_MAX, SPEED_MAX, NULL}},
  {0, WALK_BIAS, 0, MAX_DUTY, &(walk_state_t) {0, SPEED_BIAS, -SPEED_MAX, SPEED_MAX, NULL}},
};



// xorshift
uint32_t seed = 21;
uint32_t rand(){
  seed ^= seed << 13;
  seed ^= seed >> 17;
  seed ^= seed << 5;

  return seed;
}

int32_t integrate(walk_state_t * state){

  // Calculate delta from derivative or random
  int32_t x_delta;

  if(state->derivative == NULL){
    x_delta = (rand() % (SPEED_RAND_RANGE*2)) - SPEED_RAND_RANGE;
  } else {
    x_delta = integrate(state->derivative);
  }

  // Add delta
  state->x += x_delta;

  // Slowly return to bias
  state->x = (state->x*48 + state->bias*16)/64;

  // Max and Min
  if(state->x < state->min){
    state->x = state->min;
  } 
  if(state->x > state->max){
    state->x = state->max;
  }

  return state->x;

}

int main()
{
	SystemInit();
	
	// Init phase PWM timer
	track_init(&led_pwm_state);

	// Init button gpios and NVIC
	buttons_init();

	// Init timer2 and state for music
	music_init(&music_state);

	// Init systick timer
	systick_init();
	
	//I2C-------------------------

	i2c_init();

	//I2C------------------------

	
	uint32_t ms_cnt = 0;
	uint32_t next_note = 0;
	uint32_t next_button = 0;


	while(1) {

		if(ms_cnt > next_button){
			next_button = ms_cnt + 50;

			if(buttons_read_rising() == buttonMusic){

				if (music_state.playing)
				{
					music_off(&music_state);
					send_track(0xff);

				}else{
					music_change_song(&music_state, rand()%NUM_SONGS);
					music_on(&music_state);
					next_note = 0;
				}
				
			}
		}

		
		if(music_state.playing && ms_cnt > next_note){
			int8_t note = music_next_note(&music_state);
			send_track(note);
			if(note != 0xff){
				next_note = ms_cnt + music_get_current_note_duration(&music_state);
			}else{
				next_note = 0; 
			}
		}

		Delay_Ms(1);
		ms_cnt++;

	}
}


/*
 * Start up the SysTick IRQ
 */
void systick_init(void)
{
	/* disable default SysTick behavior */
	SysTick->CTLR = 0;

	/* enable the SysTick IRQ */
	NVIC_EnableIRQ(SysTicK_IRQn);

	/* Set the tick interval to 1ms for normal op */
	SysTick->CMP = (FUNCONF_SYSTEM_CORE_CLOCK / SYSTICK_INT_HZ) - 1;

	/* Start at zero */
	SysTick->CNT = 0;
	//ms_cnt = 0;

	/* Enable SysTick counter, IRQ, HCLK/1 */
	SysTick->CTLR = SYSTICK_CTLR_STE | SYSTICK_CTLR_STIE |
									SYSTICK_CTLR_STCLK;
}


/*
 * SysTick ISR just counts ticks
 * note - the __attribute__((interrupt)) syntax is crucial!
 */
void SysTick_Handler(void) __attribute__((interrupt));
void SysTick_Handler(void)
{
	// move the compare further ahead in time.
	// as a warning, if more than this length of time
	// passes before triggering, you may miss your
	// interrupt.
	SysTick->CMP += (FUNCONF_SYSTEM_CORE_CLOCK / SYSTICK_INT_HZ);

	// clear IRQ
	SysTick->SR = 0;

	// Motor advance PWM phase
	PhasePWM_setDuty(1, integrate(&(walk_states[0])) );
	PhasePWM_setDuty(2, integrate(&(walk_states[1])) );
	PhasePWM_setDuty(3, integrate(&(walk_states[2])) );
	PhasePWM_setDuty(4, integrate(&(walk_states[3])) );


}

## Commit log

2024-11-15 Clean up PWM code
2024-11-25 Adjust GPIOs for new PCB version
2024-11-26 Initial speed control and current tuning
2024-11-26 Add PCB files
    [NorthPoleCircuit_PCB.kicad_sch, bom.csv, buzzer_C391038.step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]
2024-11-27 Various silkscreen additions
    [decoration.stl, julbil.stl, julbil_V3.stl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]
2024-11-28 Continue decorations, replace QR code
    [decoration.stl]
2024-11-28 Buzzer and control inot decoration mcu
    [main.c]
2024-11-29 Create Reindeer v4.3mf
    [Reindeer v4.3mf]
2024-11-29 Final adjustments + production files
    [bom.csv, designators.csv, positions.csv]
2024-12-01 Setup i2c slave example
2024-12-01 Simple i2c master init and write example
2024-12-01 systick no work i2c, move to TIM2 IRQ
2024-12-04 Fix systick with proper interrupt nesting
    [main.c]
2024-12-05 sleigh, queen
    [sleigh.stl, sleigh_V2.stl]
2024-12-13 oh deer
    [Reindeer v4.3mf, Shuttle.stl, Sleigh.3mf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]
2024-12-16 Added production glueing photo
2024-12-21 PCB images
2024-12-21 Improve video embedding and add PCB images, as suggested in #1
2024-12-22 Add A/B diagram. Also confusion regarding magnetic forces.
2024-12-27 Fixed U3/U4 rotation in position file
    [positions.csv]
